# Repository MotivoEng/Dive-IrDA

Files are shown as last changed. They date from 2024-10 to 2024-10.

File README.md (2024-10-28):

# Dive-IrDA
A USB-to-IrDA transceiver intended for use with some Cressi dive computers.
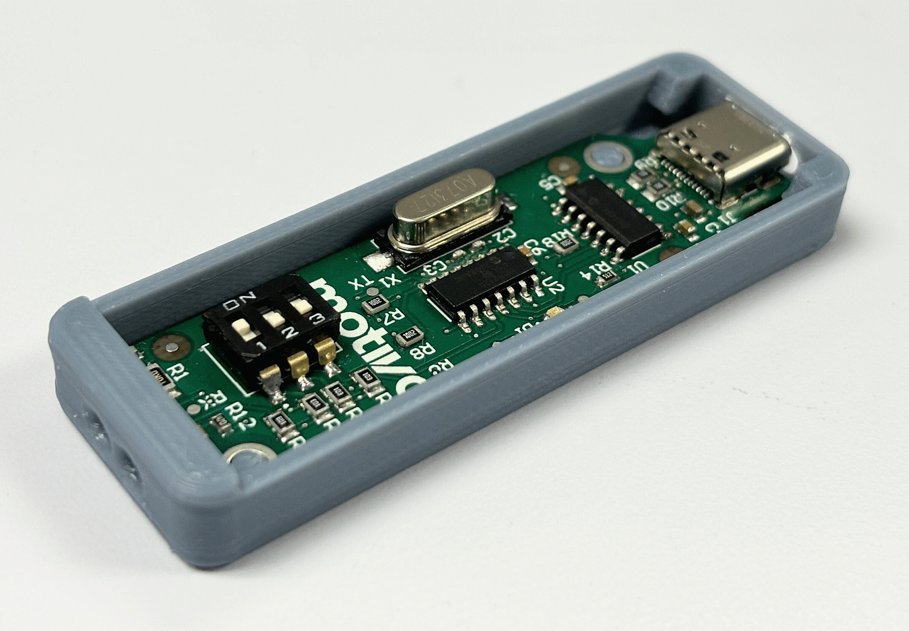
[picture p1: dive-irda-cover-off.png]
Dive PCBA in enclosure base


## General Description

This project arose due to the extreme difficulty in finding and purchasing Cressi's official Bluetooth/USB transceiver interface for the "big screen" dive computers for a reasonable amount of money. In small quantities (~10), we have been able to produce devices for around $30 USD each.

This device uses all off-the-shelf parts to form a serial transceiver between a USB port and an IrDA transceiver module capable of 115200 baud. It does this in a chain of three ICs:

- MCP2221A: USB to UART transceiver
- MCP2120T: UART to IrDA encoder-decoder
- TFBS4650: IR photodiode-emitter pair with internal driver

The above creates a device that should work as a generic IrDA transceiver, though it has only been tested or its intended use: with specific Cressi dive computers. See below section for dive computer model compatibility. 
 
## License

This repository and its design files are licensed under **CERN-OHL-S**, also known as _CERN Open Hardware Licence Version 2 - Strongly Reciprocal._ The following intents are imparted by this license:

 - The design is modifiable and distributable as long as attribution and source is provided downstream.
 -  You may manufacture and sell devices based on this original design or a modification of it, as long as attribution and source is provided downstream. 
 - We assume no liability and provide no warranty for the functionality of the design.
 - You may **not** take or repackage this design and sell it as digital design package. All distributions must contain and carry out the intent of the license.  

## Compatibility

In our **limited** testing with the [Subsurface](https://subsurface-divelog.org/) open source dive logging application, we have so far discovered these compatibilities:
| Manufacturer | Model | Works? | Notes |
|--|--|--|--|
| Cressi | Giotto (presumably "1.0") | ✅ | Tested on Linux (Ubuntu 22), MacOS (13), Windows (10, 11)
| Cressi | Leonardo (presumably "1.0") | ✅ | Tested on Linux (Ubuntu 22), MacOS (13, 14), Windows (10, 11)
| Cressi | Donatello 2.0 | ❓ | Will likely work in the future, [ongoing work here](https://github.com/subsurface/libdc/issues/67).
| Cressi | Michelangelo | ❓ | Might work, given similarity to other computers
| Galileo | Sol | ❌ | Subsurface only supports native IrDA adapters for the Galileo Sol, not IrDA-to-USB-Serial devices like ours.

At this time, the common OEM dive log downloader apps do not work with our device. We don't intend on supporting these apps in the future, but encourage others to fork this project or concepts from it to create compatibility with other dive computers!

## Source Files

This repo contains the original source files for Altium (PCB design) and Solidworks (3D printed enclosure design). It also contains files for manufacturing the PCBA (Gerbers and drills, bill of materials, pick-and-place). 

## Usage

We have written a very basic "quick start" manual which can be found [here](USB%20to%20IRDA%20Kit%20User%20Guide.pdf).

Initial discussion about the device began [here](https://groups.google.com/g/subsurface-divelog/c/ku56SSlCtZU/m/znZ3TwYTBwAJ).

## Thanks
Project development was undertaken by Teddy Huffer (electrical and mechanical design) and Daniel Samarin (architecture, concept of operation) while working at [Motivo](https://www.motivo.com/). Motivo sponsored the time and materials for this project.

Also thanks to our beta testers that contributed their time and money (for shipping costs) to testing our device with their dive computers: Chris, Katherine, Charles, Ivar, Robert, Anthony, Yann.

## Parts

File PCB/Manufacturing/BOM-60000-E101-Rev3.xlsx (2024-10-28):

BOM Number: |  | 60000-D003 |  | 60000 | D003
Project Revision: |  | Rev 3
Code Name: |  | DIVE
Customer PN: |  | TBD
Customer Rev: |  | TBD
RoHS Compliant Solder Process (Y/N) |  | TBD
Reference Documents |  | Document Number
Schematic: |  | 60000-D001-Rev3 |  | 60000 | D001 | Rev3
Fabrication/Assembly Drawing: |  | 60000-D002-Rev 2 |  | 60000 | D002 | Rev 2
PCB Number / Gerbers |  | 60000-E101-Rev 3 |  | 60000 | E101 | Rev 3
*Firmware: |  | TBD
Test Specification: |  | TBD
*Firmware to be programmed on to (TBD)
Item # | Quantity | Designator | Manufacturer 1 | Manufacturer Part Number 1 | Manufacturer 2 | Manufacturer Part Number 2 | Description
1 | 2 | C1, C4 | TDK | C1608X5R1C475K080AC |  |  | CAP CER 4.7UF 16V X5R 0603
2 | 2 | C2, C3 | Yageo | CC0402JRNPO9BN360 |  |  | CAP CER 36PF ±5% 50V C0G/NPO 0402
3 | 3 | C5, C6, C7 | Wurth Electronics | 885012206020 |  |  | CAP CER 0.1UF 10V X7R 0603
4 | 1 | C8 | Samsung | CL10B474KA8VPNC |  |  | CAP CER 0.47UF 25V X7R 0603
5 | 1 | D1 | Vishay Lite-On | LTST-C190GKT |  |  | LED GREEN CLEAR CHIP SMD
6 | 1 | J1 | Hirose | CX90B1-24P |  |  | CONN RCP USB3.1 TYPEC 24P SMD RA
7 | 1 | PCB1 | Vendor to Source | PCB-60000-E101-Rev 3 |  |  | Bare PCB - Gerber/Drill/Pick and Place Data
8 | 1 | R1 | Stackpole Electronics | RNCP1206FTD10R0 |  |  | RES 10 OHM 1% 1/2W 1206
9 | 4 | R2, R3, R4, R5 | Stackpole Electronics | RMCF0805FT10K0 | Yageo | RC0805FR-0710KL | RES 10K OHM 1% 1/8W 0805
10 | 4 | R6, R7, R8, R18 | Yageo | RC0603FR-0710KL |  |  | RES SMD 10K OHM 1% 1/10W 0603
11 | 2 | R9, R10 | Vishay Dale | CRCW080510R0JNEA |  |  | RES SMD 10 OHM 5% 1/8W 0805
12 | 1 | R11 | Yageo | RC0603FR-072K2L |  |  | RES 2.20K OHM 1/10W 1% 0603 SMD
13 | 1 | R12 | Stackpole Electronics | RMCF0603FT47R0 |  |  | RES 47 OHM 1% 1/10W 0603
14 | 2 | R13, R14 | Vishay Dale | CRCW06035K10JNEA |  |  | RES SMD 5.1K OHM 5% 1/10W 0603
15 | 3 | R15, R16, R17 | Yageo | RC0603JR-070RL | Rohm | MCR03ERTJ000 | RES SMD 0.0OHM JUMPER 1/10W 0603
16 | 1 | SW1 | Omron | A6S-3102-H | Omron | A6S-3102-PH | SWITCH SLIDE DIP SPST 25MA 24V
17 | 1 | U1 | Microchip | MCP2221A-I/SL |  |  | IC USB TO I2C/UART 14SOIC
18 | 1 | U2 | Microchip | MCP2120T-I/SL |  |  | IC ENCODR/DECODR 2.5V IR 14-SOIC
19 | 1 | U3 | Vishay | TFBS4650-TR1 |  |  | TXRX IRDA 115.2KBIT SIDE 7-SMD / Infrared Transceiver 9.6 kbit/s to 115.2 kbit/s (SIR)
20 | 1 | X1 | YXC Crystal Oscillators | X49SM73728MSD2SC-1 |  |  | 7.3728MHz 20pF ±20ppm HC-49S-SMD Crystals ROHS

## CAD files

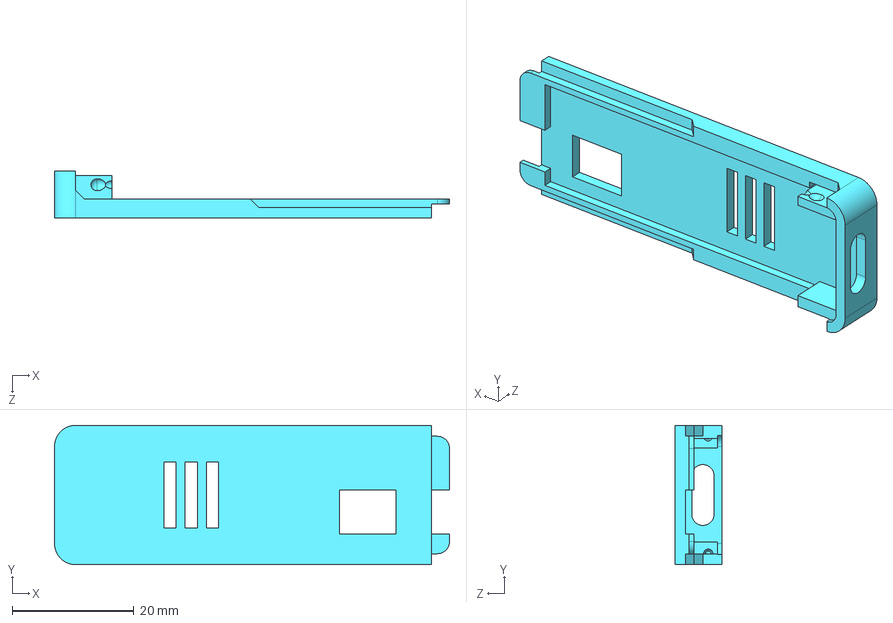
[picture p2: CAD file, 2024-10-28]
CAD/STEP/Sliding_lid.STEP
65.0 x 22.9 x 7.70 mm

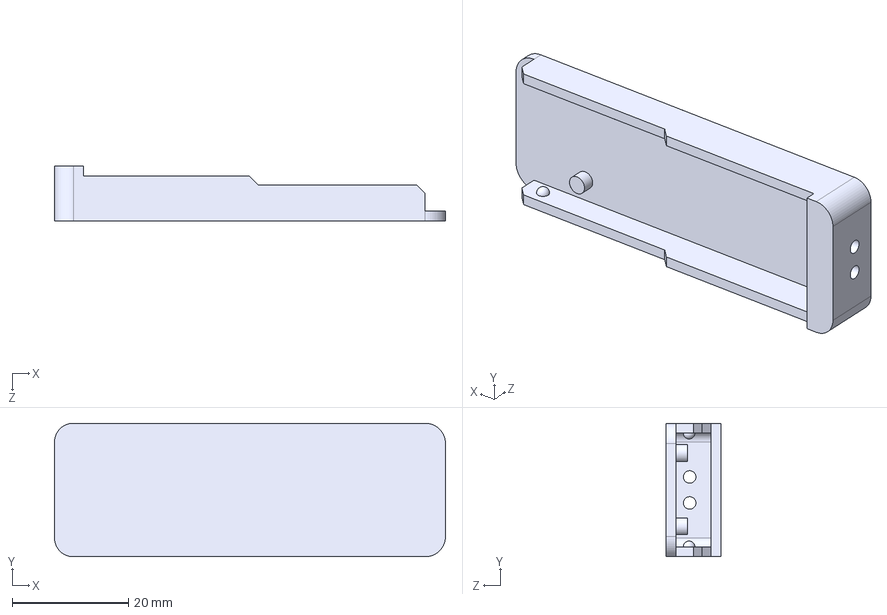
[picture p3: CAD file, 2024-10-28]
CAD/STEP/Enclosure_Base.STEP
67.2 x 22.9 x 9.40 mm

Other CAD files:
CAD/USB_to_IRDA_2.step.SLDASM
CAD/Enclosure_base.SLDPRT
CAD/STL/Enclosure_base.STL
CAD/STL/Sliding_lid.STL
CAD/Sliding_lid.SLDPRT

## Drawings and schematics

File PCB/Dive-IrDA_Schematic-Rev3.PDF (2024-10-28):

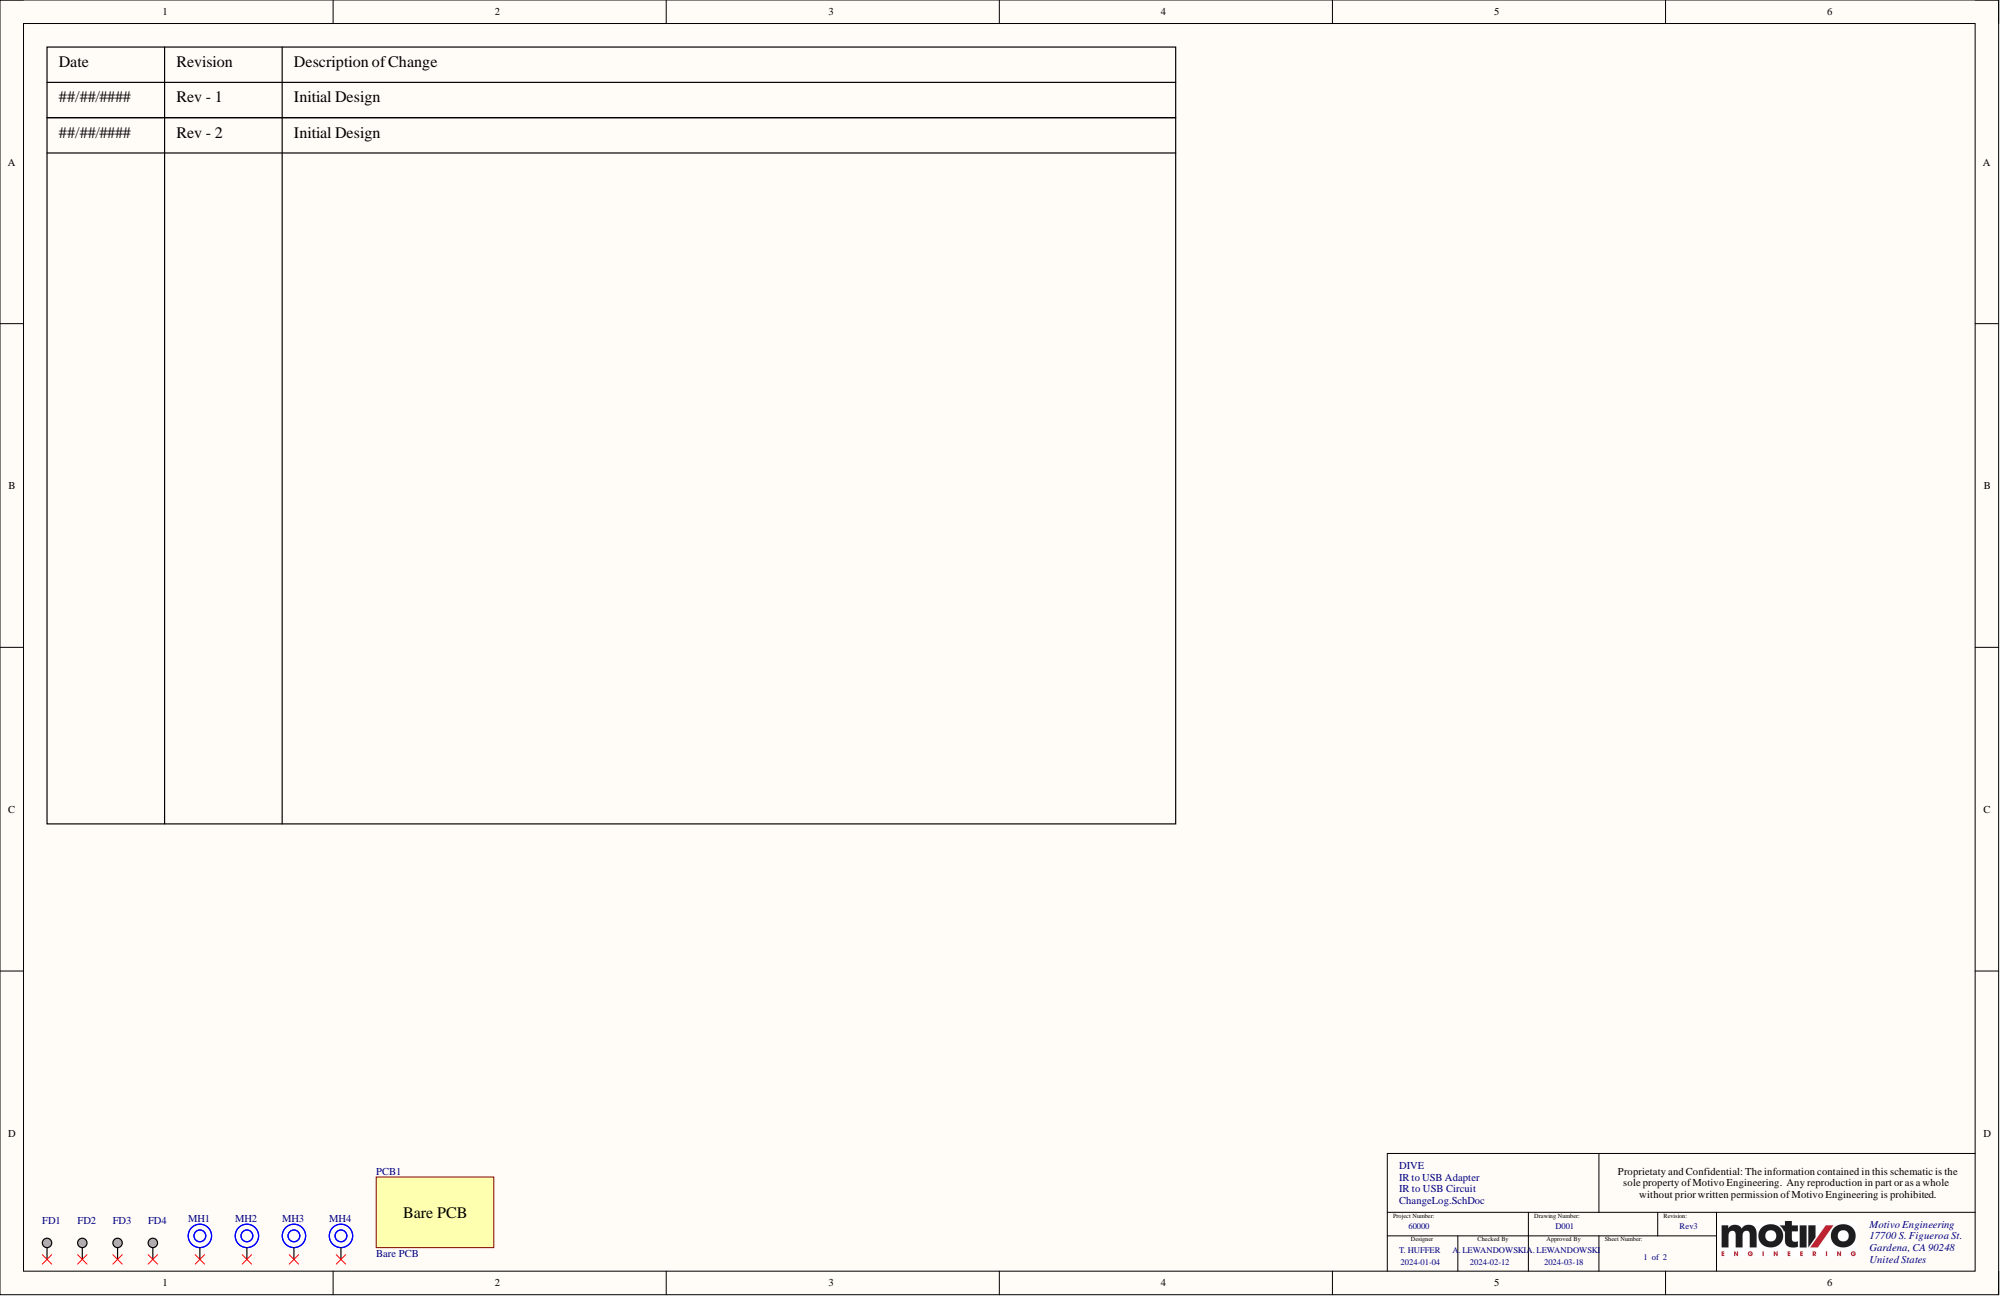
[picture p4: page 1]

Date | Revision | Description of Change

##/##/#### | Rev - 1 | Initial Design

##/##/#### | Rev - 2 | Initial Design

DIVE
IR to USB Adapter
IR to USB Circuit
ChangeLog.SchDoc

Proprietaty and Confidential: The information contained in this schematic is the
sole property of Motivo Engineering. Any reproduction in part or as a whole
without prior written permission of Motivo Engineering is prohibited.

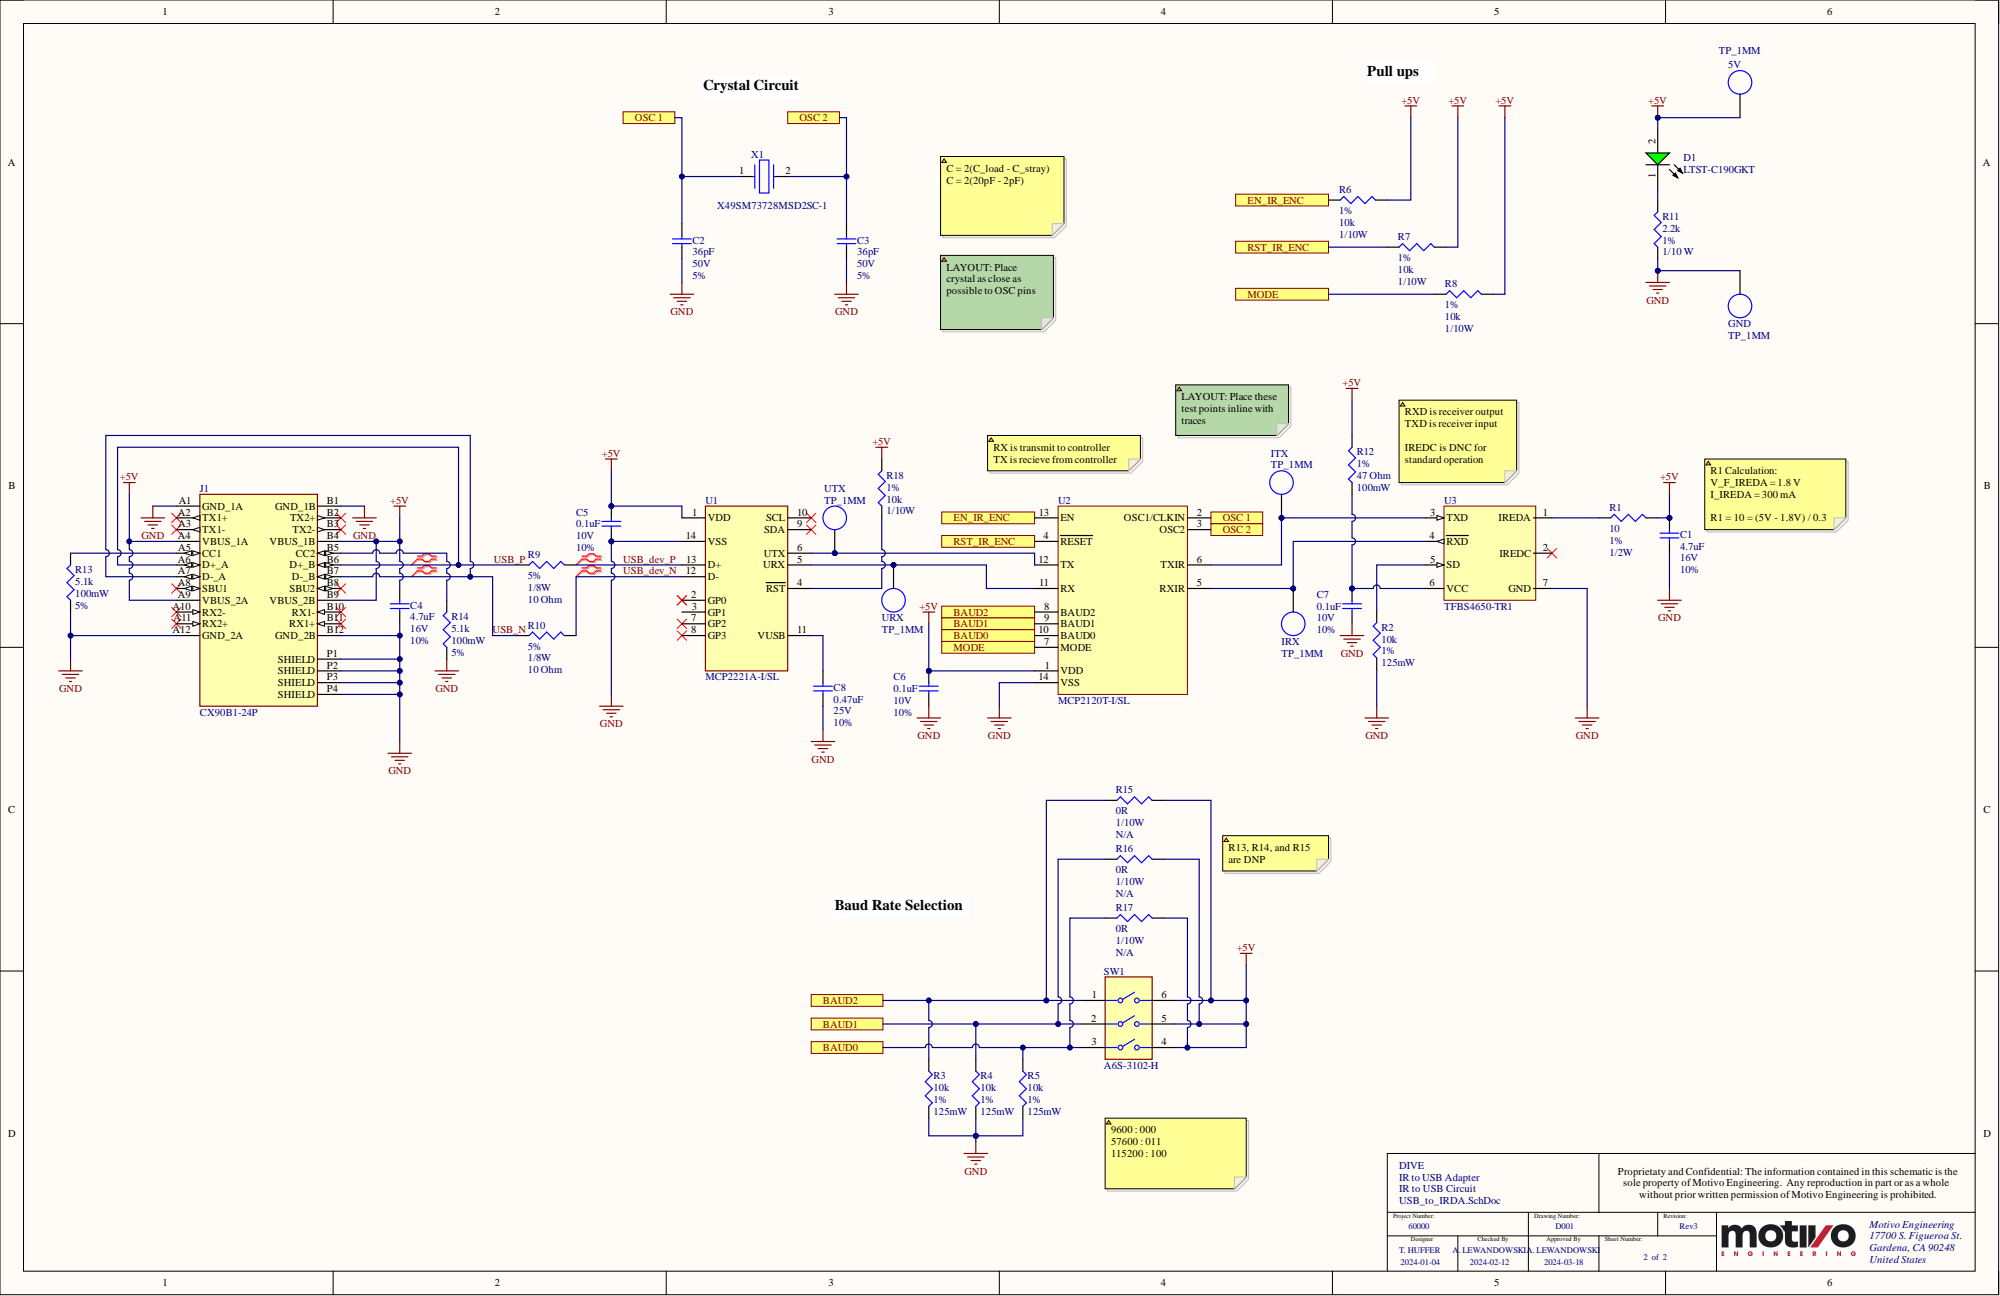
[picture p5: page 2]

LAYOUT: Place
crystal as close as
possible to OSC pins

LAYOUT: Place these
test points inline with
traces

RXD is receiver output
TXD is receiver input

RX is transmit to controller
TX is recieve from controller

IREDC is DNC for
standard operation

DIVE
IR to USB Adapter
IR to USB Circuit
USB_to_IRDA.SchDoc

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

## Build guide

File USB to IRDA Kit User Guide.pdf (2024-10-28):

Rev 2

# USB to IRDA Kit User Guide

## Kit Contents

Component Name | Part Number
USB to IRDA PCBA | 60000-E101
Device Enclosure | 60000-M101
Enclosure Lid | 60000-M102
USB type C cable | Amazon B07R14JVGW

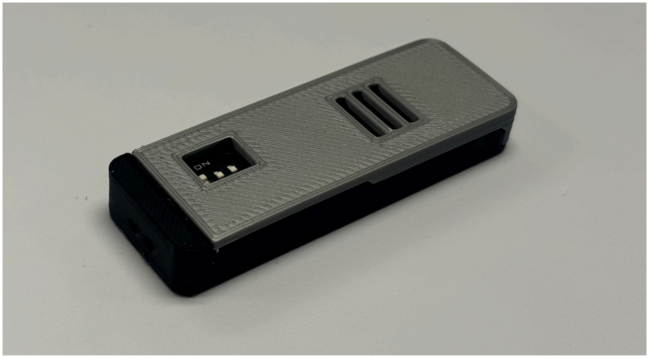
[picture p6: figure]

### Instructions

1. Adjust the switches to match the baud rate of your dive computer using the baud rate table below.
Switch configuration shown is for Cressi dive computers Baud Rate Table
Baud Rate | Dive Computer Brands | Switch configuration
1 | 2 | 3
9600 | Mares | OFF | OFF | OFF
19200 | Galileo | OFF | OFF | ON
38400 | | OFF | ON | OFF
57600 | | OFF | ON | ON
115200 | Cressi | ON | OFF | OFF
2. Connect the device to your computer with the USB cable. A red light should shine through the hole in the enclosure.
3. Identify the Serial Port to which the device has connected
a. Windows:
i. Open Device Manager
ii. Scroll down to the Ports (COM & LPT) section and identify the port that has opened when you plugged the device in.

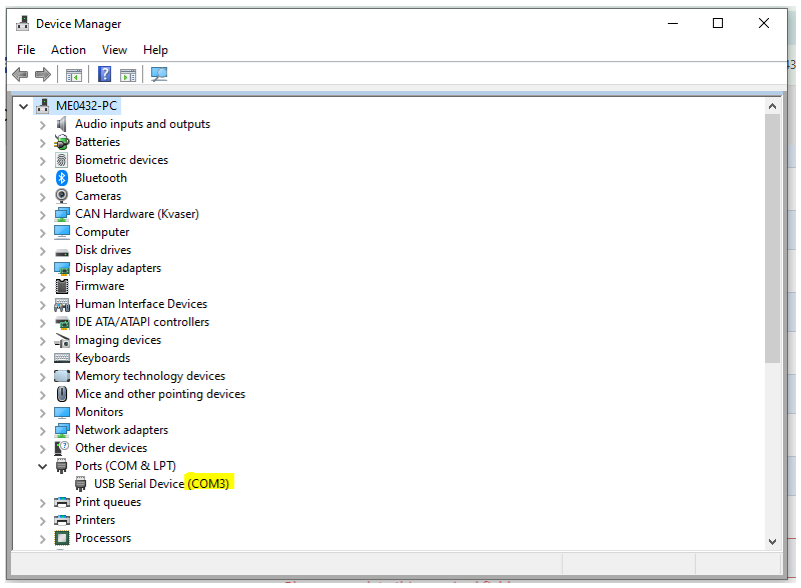
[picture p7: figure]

b. MacOS:
i. From the Applications menu, open the Utilities Folder and then System Information
ii. | Scroll down to the USB section and open the USB Device
| Tree
iii. | Select the device called “MCP2221USB-I2C/UART Combo”
iv. | In the Location ID for this device, note the first 5 numbers after the 0x

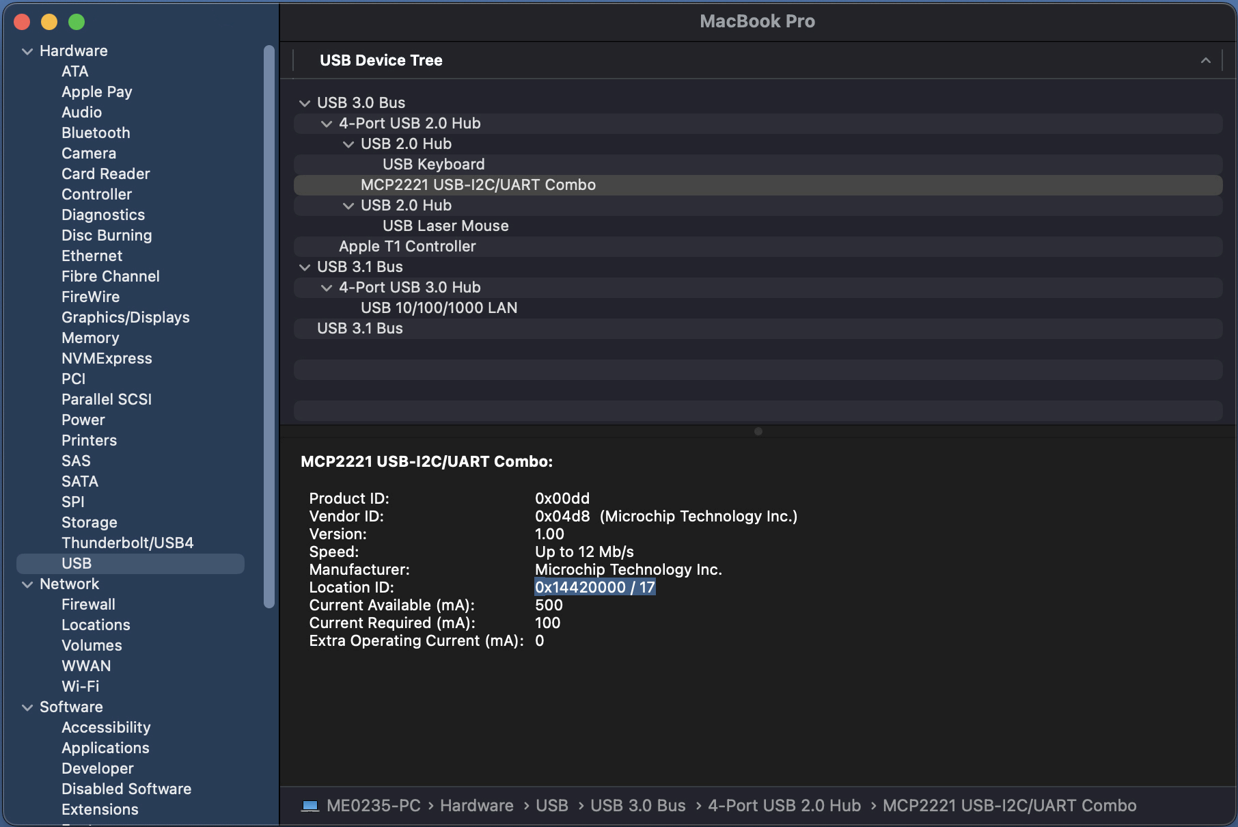
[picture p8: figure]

4. Open the Subsurface app on your computer and select Import->Import from dive computer

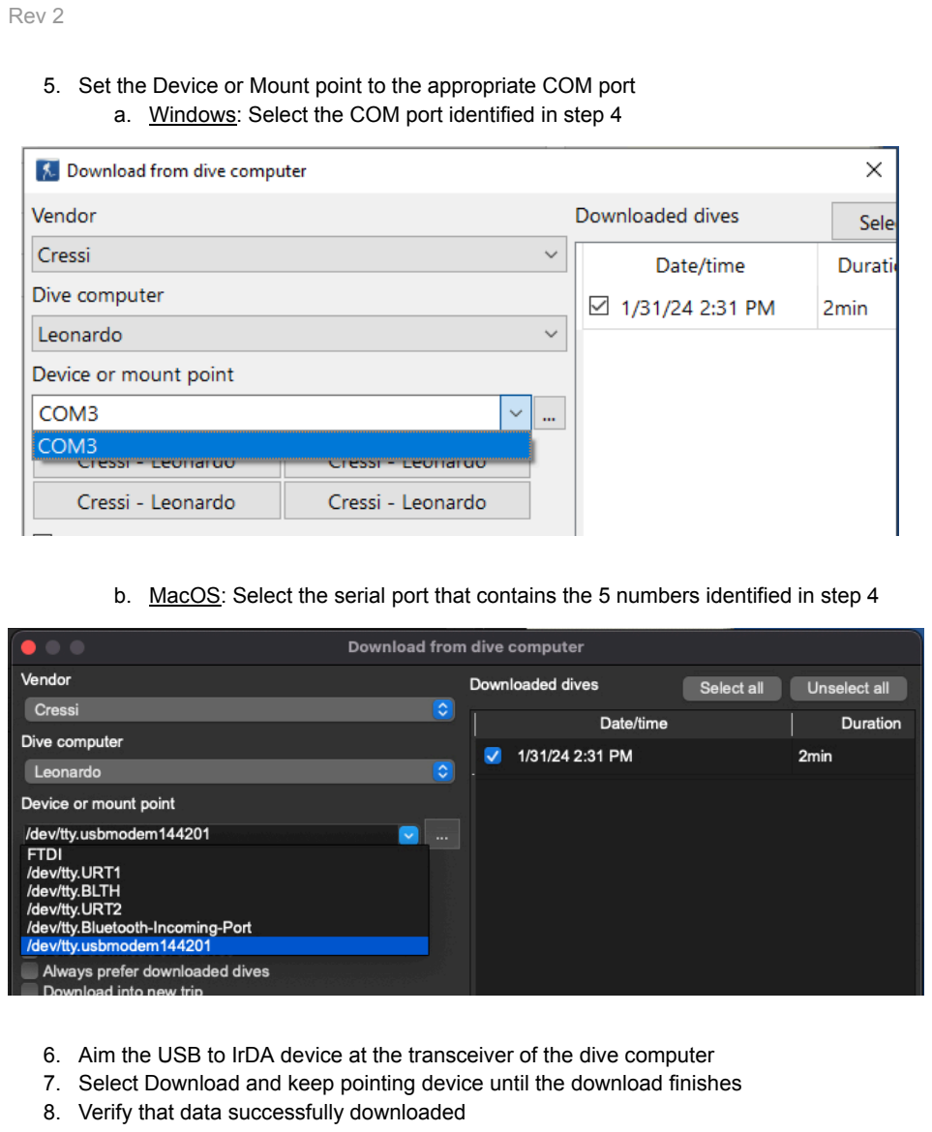
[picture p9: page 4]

5. Set the Device or Mount point to the appropriate COM port
a. Windows: Select the COM port identified in step 4
b. MacOS: Select the serial port that contains the 5 numbers identified in step 4
6. Aim the USB to IrDA device at the transceiver of the dive computer
7. Select Download and keep pointing device until the download finishes
8. Verify that data successfully downloaded
